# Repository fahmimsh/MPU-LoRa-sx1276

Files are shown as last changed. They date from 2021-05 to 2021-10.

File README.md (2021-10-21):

# MPU-LoRa-sx1276 ESP32 as GATEWAY and Arduino Promini as node multi connection communication
let's get developt it together
This repository program is used for monitoring public transportation such as metroline, MPU, and so on. There are 2 programs, namely node programs installed in vehicles by sending GPS data and gateway programs to receive data from node x vehicles to be sent to the database. Then the passenger android application will be able to find out the location of the vehicle closest to the location of the passenger vehicle.

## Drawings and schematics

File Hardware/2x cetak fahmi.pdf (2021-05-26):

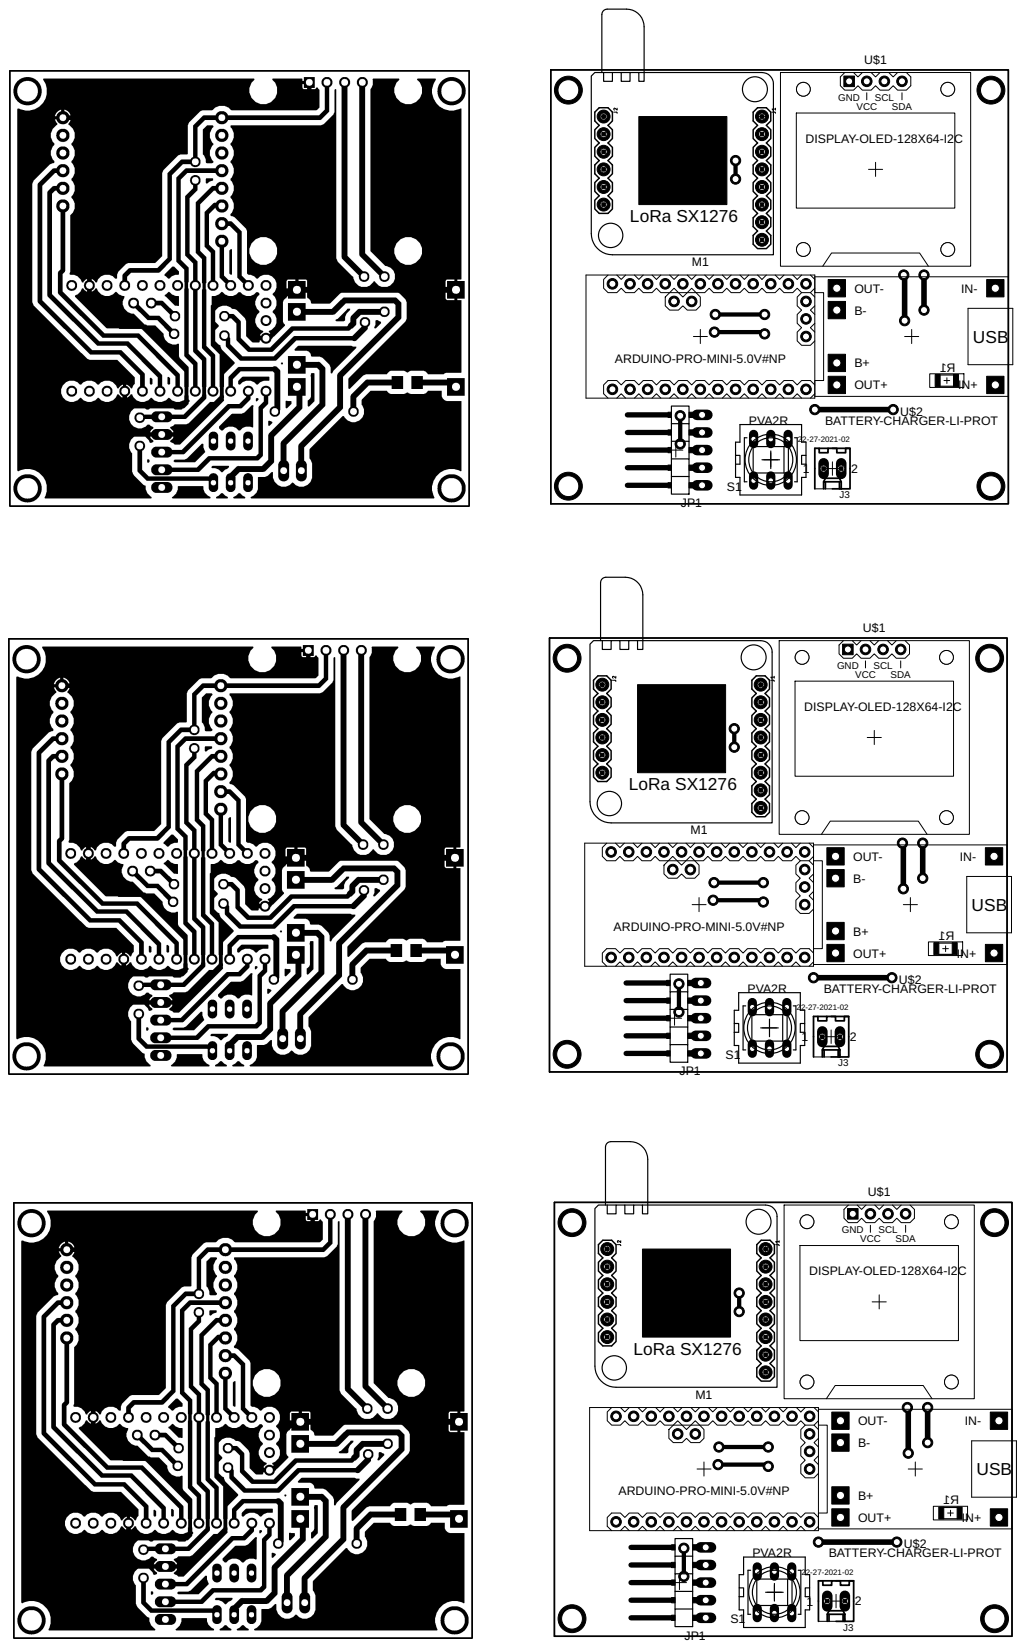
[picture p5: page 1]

ARDUINO-PRO-MINI-5.0V#NP

U$2 BATTERY-CHARGER-LI-PROT

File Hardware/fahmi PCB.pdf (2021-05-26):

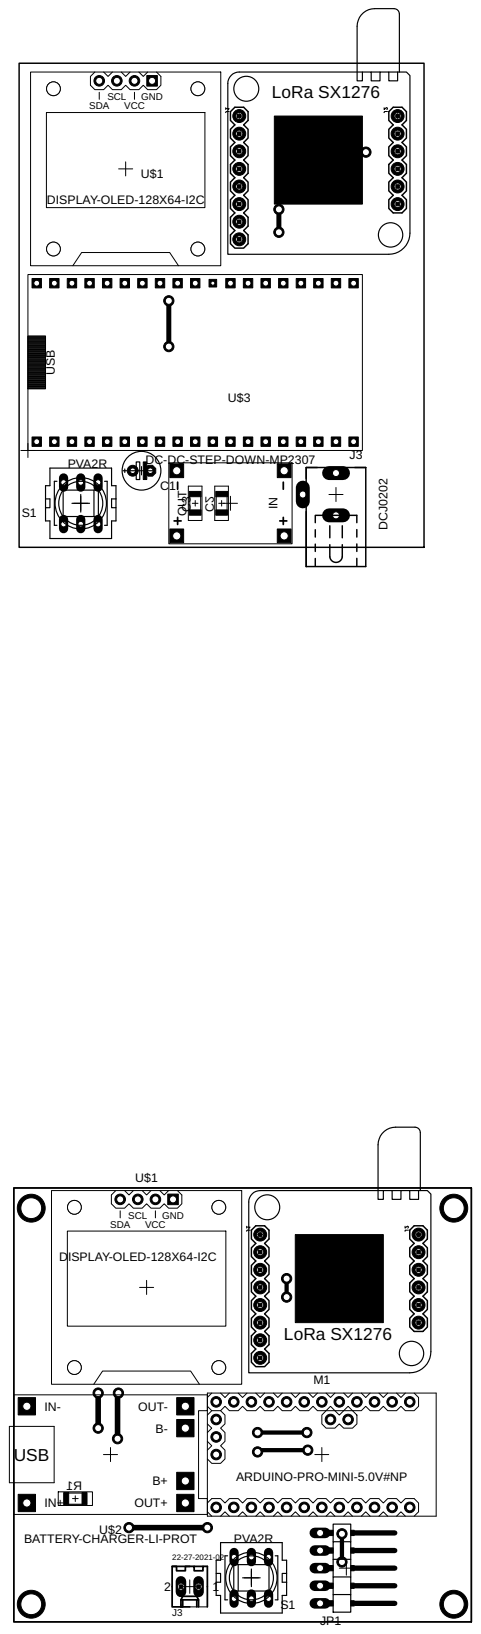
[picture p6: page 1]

ARDUINO-PRO-MINI-5.0V#NP

U$2 BATTERY-CHARGER-LI-PROT

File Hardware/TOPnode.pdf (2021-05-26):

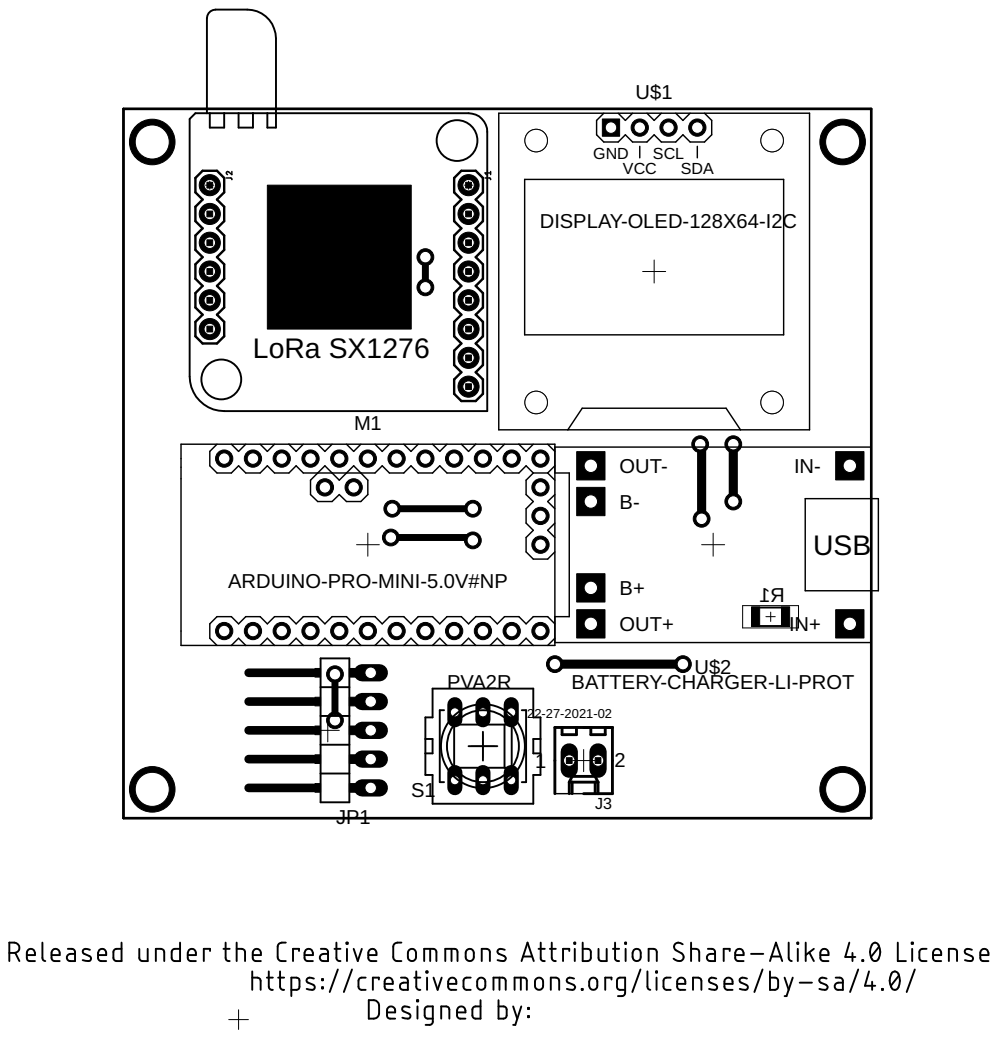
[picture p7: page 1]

ARDUINO-PRO-MINI-5.0V#NP

BATTERY-CHARGER-LI-PROT

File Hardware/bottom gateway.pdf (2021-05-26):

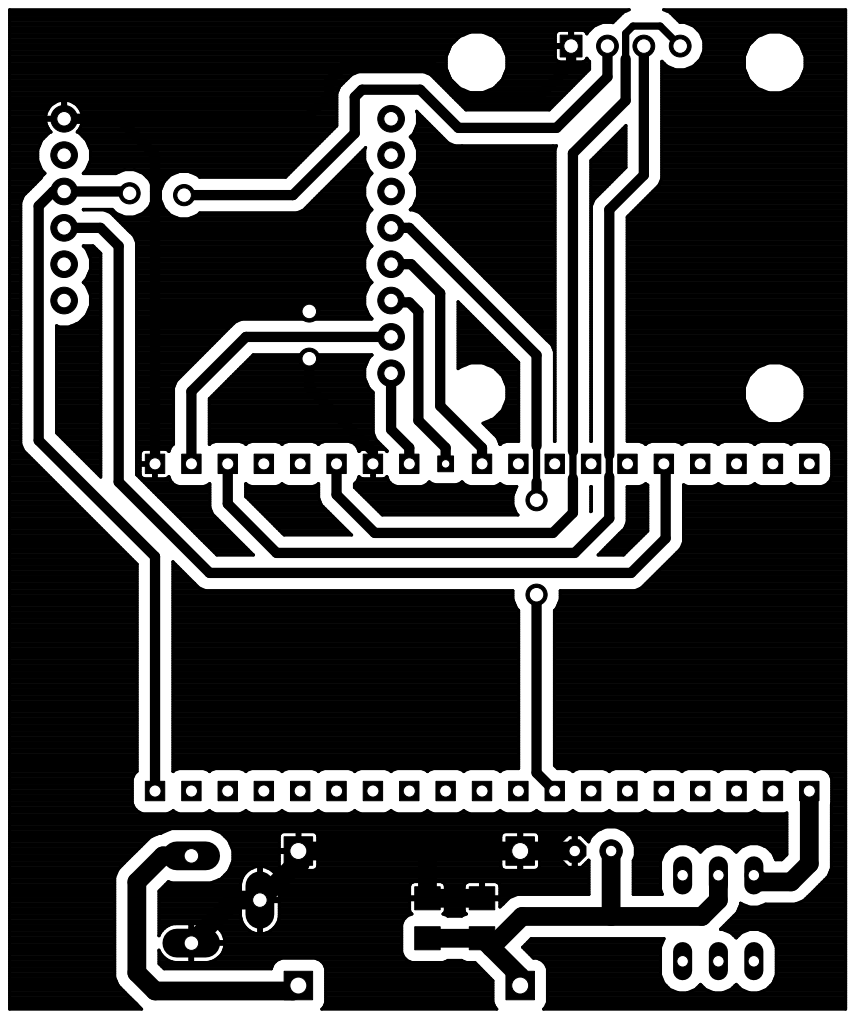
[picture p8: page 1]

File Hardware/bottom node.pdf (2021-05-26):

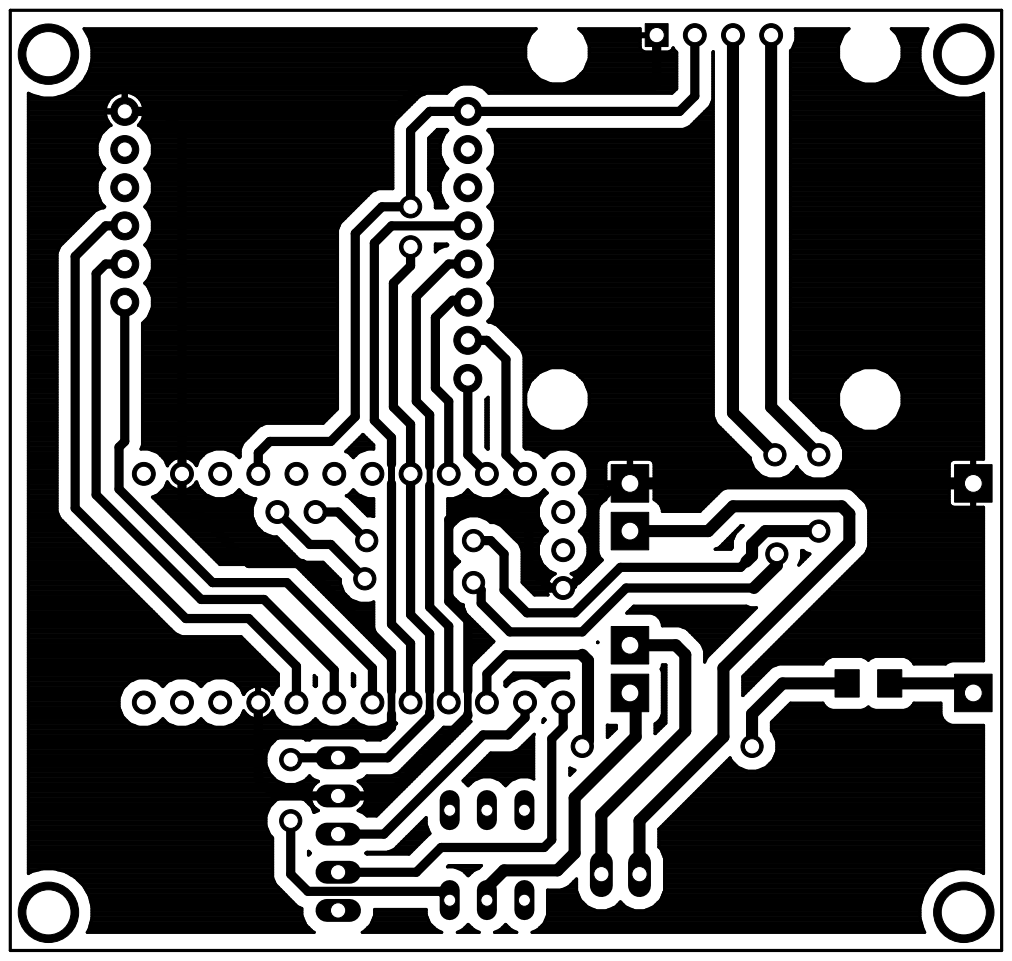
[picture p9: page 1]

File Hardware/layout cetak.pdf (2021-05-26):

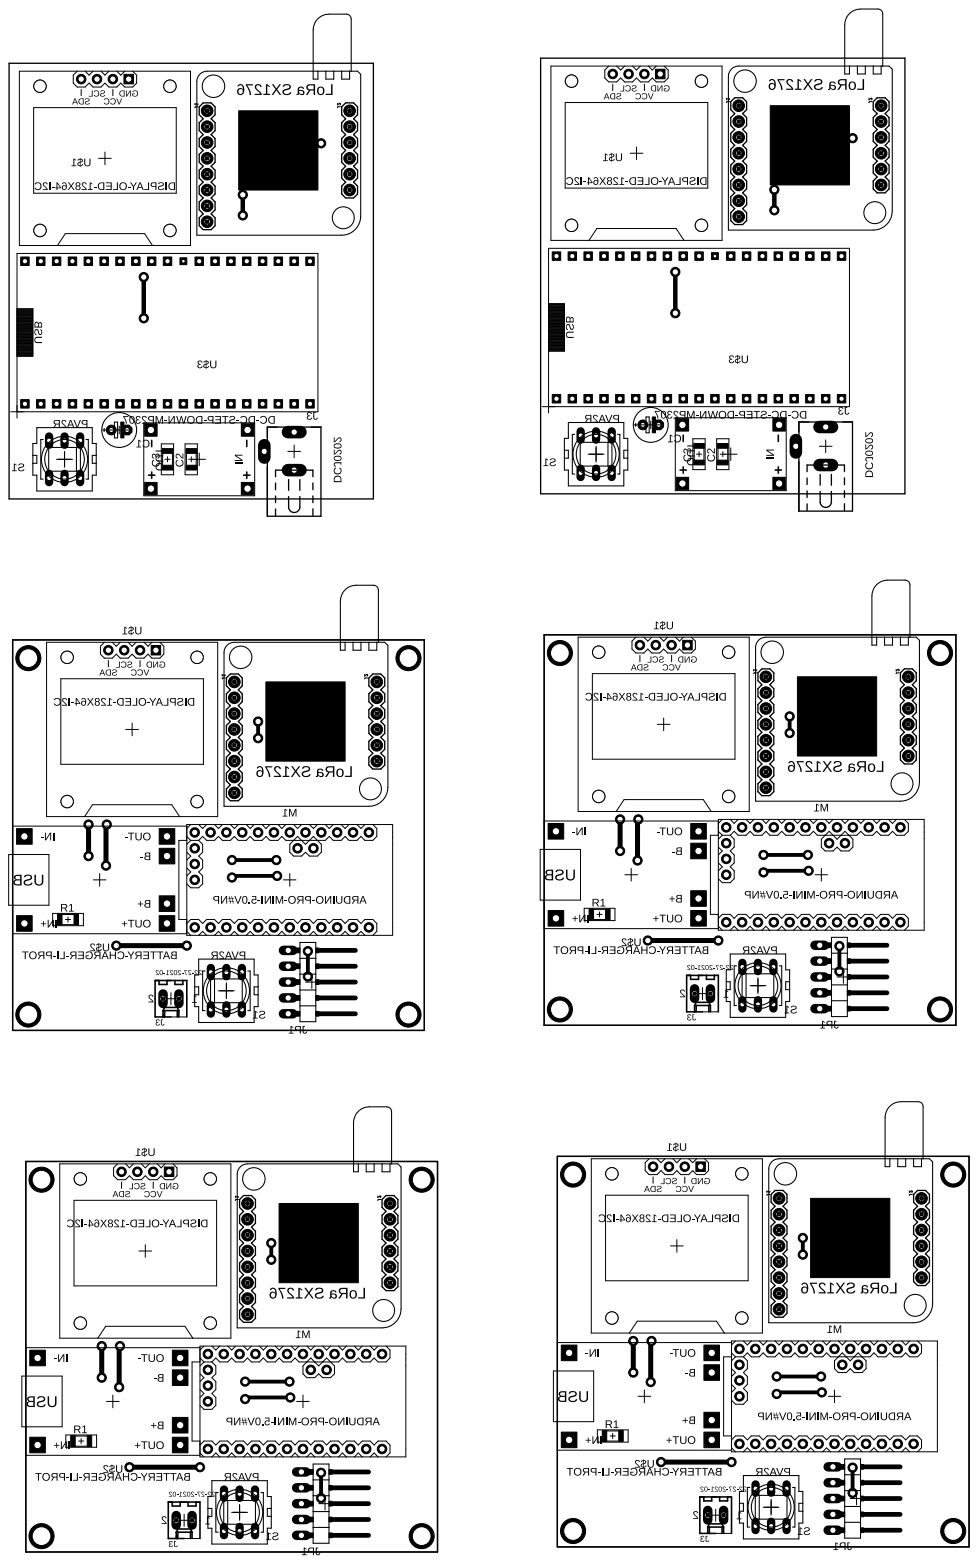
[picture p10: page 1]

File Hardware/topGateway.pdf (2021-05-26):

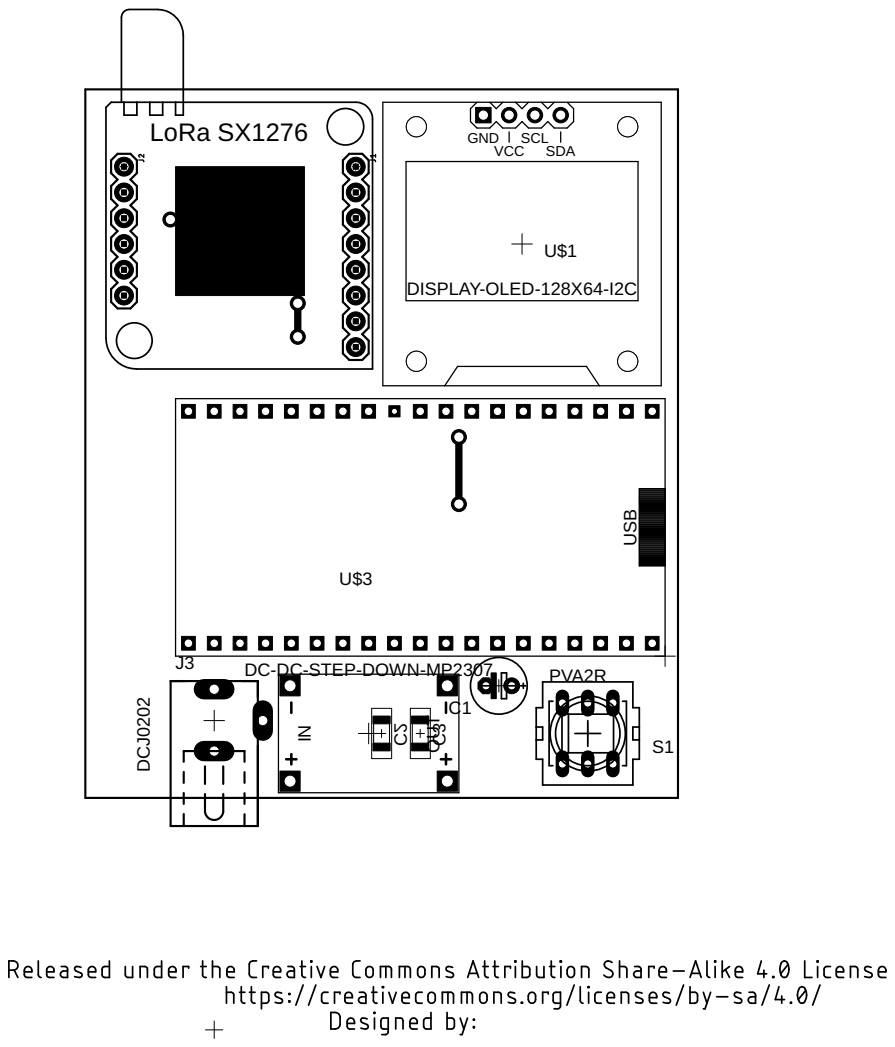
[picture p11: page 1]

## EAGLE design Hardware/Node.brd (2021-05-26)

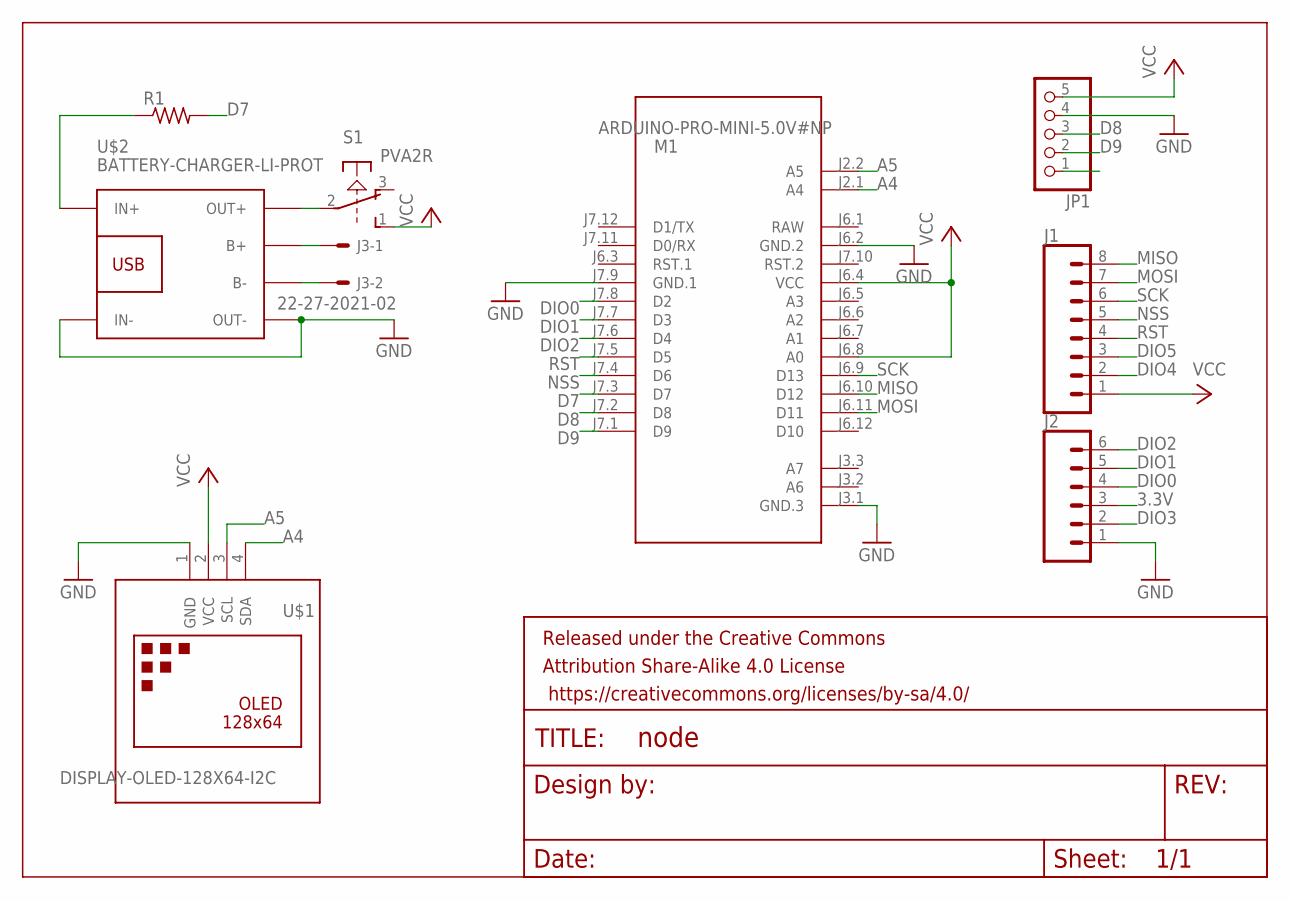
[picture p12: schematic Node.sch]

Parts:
FRAME1: FRAME-LEDGER; CREATIVE_COMMONS
J1: CONN_08"; 1X08
J2: CONN_06SILK_FEMALE_PTH; 1X06
J3: 22-27-2021-02; 6410-02
JP1: PINHD-1X5/90; 1X05/90
M1: ARDUINO-PRO-MINI-5.0V#NP; ARDUINO-PRO-MINI#NP
R1: R-US_R1206; R1206
S1: PVA2R
U$1: DISPLAY-OLED-128X64-I2C
U$2: BATTERY-CHARGER-LI-PROT

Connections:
3.3V: J2.3
A4: M1.J2.1 (A4), U$1.4 (SDA)
A5: M1.J2.2 (A5), U$1.3 (SCL)
D7: M1.J7.3 (D7), R1.2
D8: JP1.3, M1.J7.2 (D8)
D9: JP1.2, M1.J7.1 (D9)
DIO0: J2.4, M1.J7.8 (D2)
DIO1: J2.5, M1.J7.7 (D3)
DIO2: J2.6, M1.J7.6 (D4)
DIO3: J2.2
DIO4: J1.2
DIO5: J1.3
GND: J2.1, JP1.4, M1.J3.1 (GND.3), M1.J6.2 (GND.2), M1.J7.9 (GND.1), U$1.1 (GND), U$2.IN-, U$2.OUT-
MISO: J1.8, M1.J6.10 (D12)
MOSI: J1.7, M1.J6.11 (D11)
unnamed: R1.1, U$2.IN+
unnamed: J3.1, U$2.B+
unnamed: J3.2, U$2.B-
unnamed: S1.2, U$2.OUT+
NSS: J1.5, M1.J7.4 (D6)
RAW: M1.J6.1 (RAW)
RST: J1.4, M1.J7.5 (D5)
SCK: J1.6, M1.J6.9 (D13)
VCC: J1.1, JP1.5, M1.J6.4 (VCC), M1.J6.8 (A0), S1.1 (S), U$1.2 (VCC)

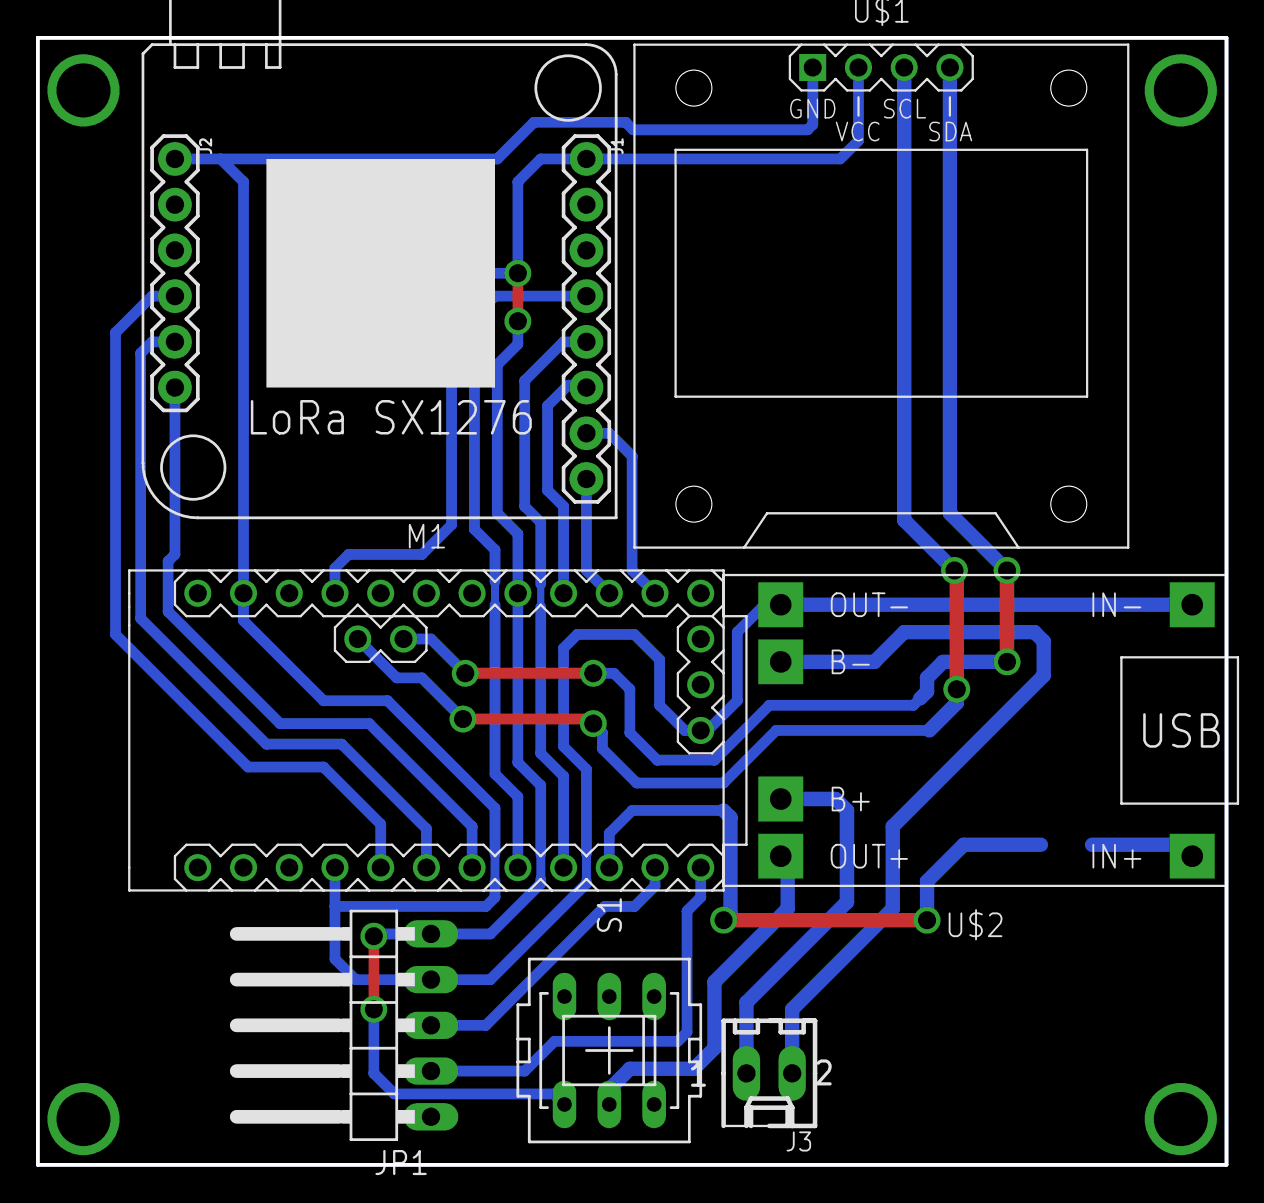
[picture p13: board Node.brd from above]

Board: 2 copper layers, 66.0 x 62.6 mm, 10 parts (1 on the bottom side), 19 nets.

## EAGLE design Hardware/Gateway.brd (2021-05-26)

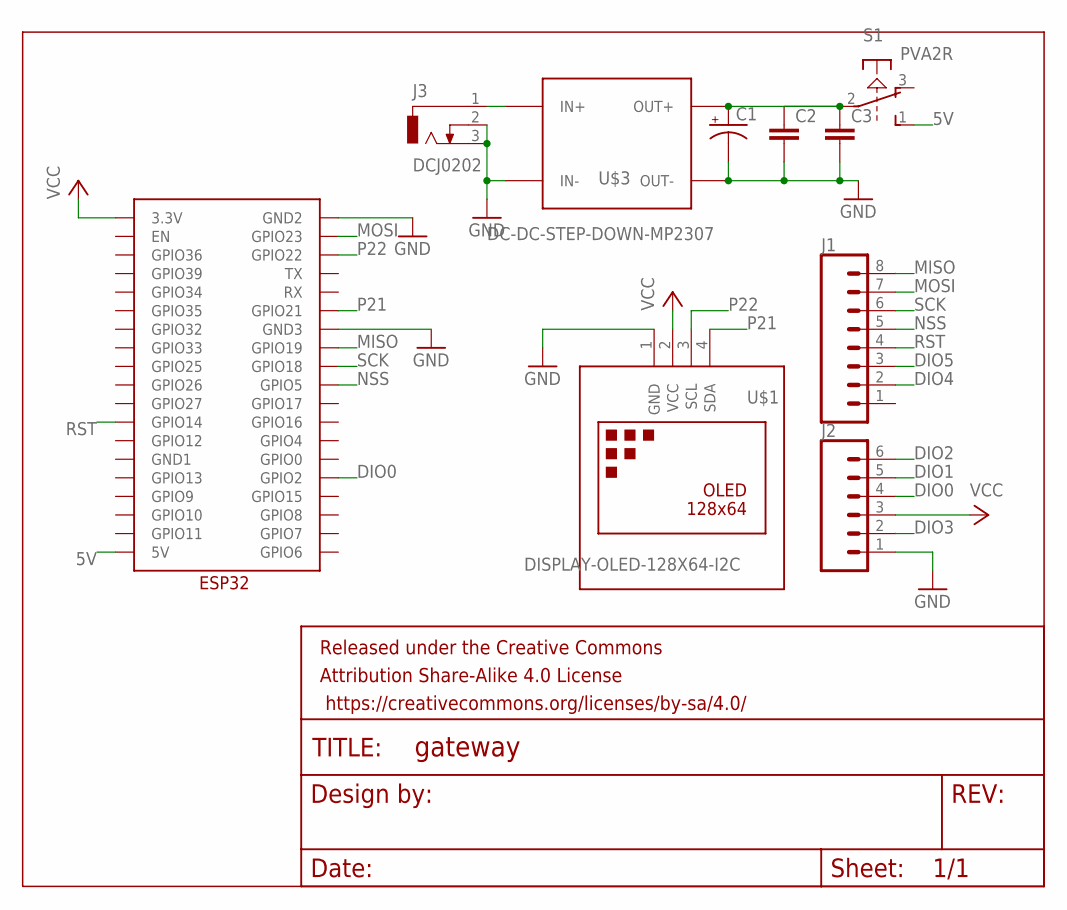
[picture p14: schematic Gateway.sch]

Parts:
C1: CPOL-USE2,5-6E; E2,5-6E
C2, C3: C-EUC1206; C1206
FRAME1: FRAME-LEDGER; CREATIVE_COMMONS
J1: CONN_08"; 1X08
J2: CONN_06SILK_FEMALE_PTH; 1X06
J3: DCJ0202
S1: PVA2R
U$1: DISPLAY-OLED-128X64-I2C
U$2: ESP32
U$3: DC-DC-STEP-DOWN-MP2307

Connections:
5V: S1.1 (S), U$2.5V
DIO0: J2.4, U$2.GPIO2
DIO1: J2.5
DIO2: J2.6
DIO3: J2.2
DIO4: J1.2
DIO5: J1.3
GND: C1.-, C2.2, C3.2, J2.1, J3.2, J3.3, U$1.1 (GND), U$2.GND2, U$2.GND3, U$3.IN-, U$3.OUT-
MISO: J1.8, U$2.GPIO19
MOSI: J1.7, U$2.GPIO23
unnamed: C1.+, C2.1, C3.1, S1.2, U$3.OUT+
unnamed: J3.1, U$3.IN+
NSS: J1.5, U$2.GPIO5
P21: U$1.4 (SDA), U$2.GPIO21
P22: U$1.3 (SCL), U$2.GPIO22
RST: J1.4, U$2.GPIO14
SCK: J1.6, U$2.GPIO18
VCC: J2.3, U$1.2 (VCC), U$2.3.3V

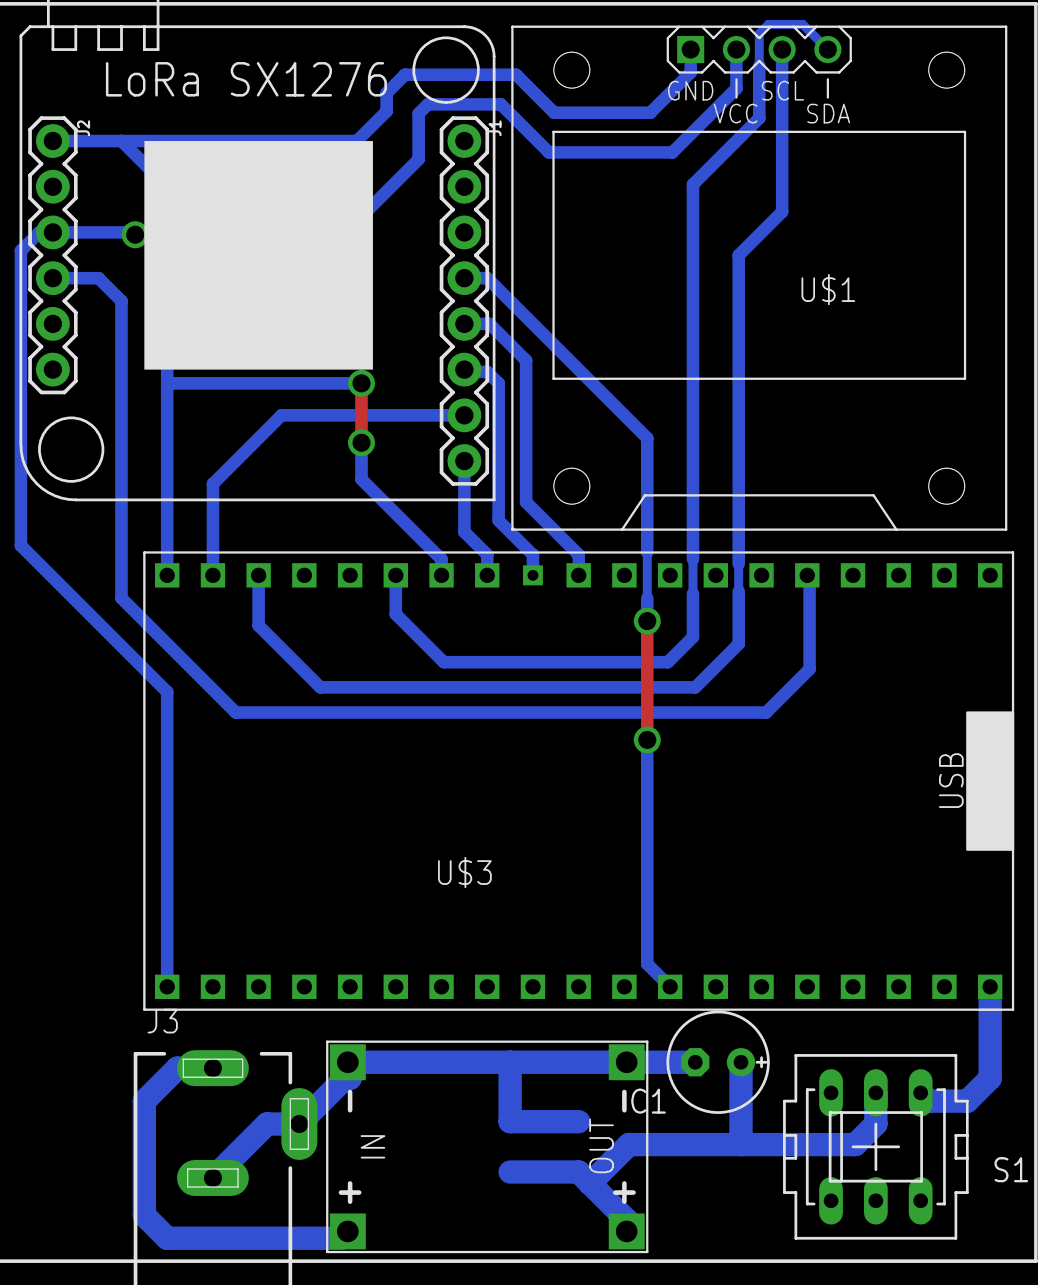
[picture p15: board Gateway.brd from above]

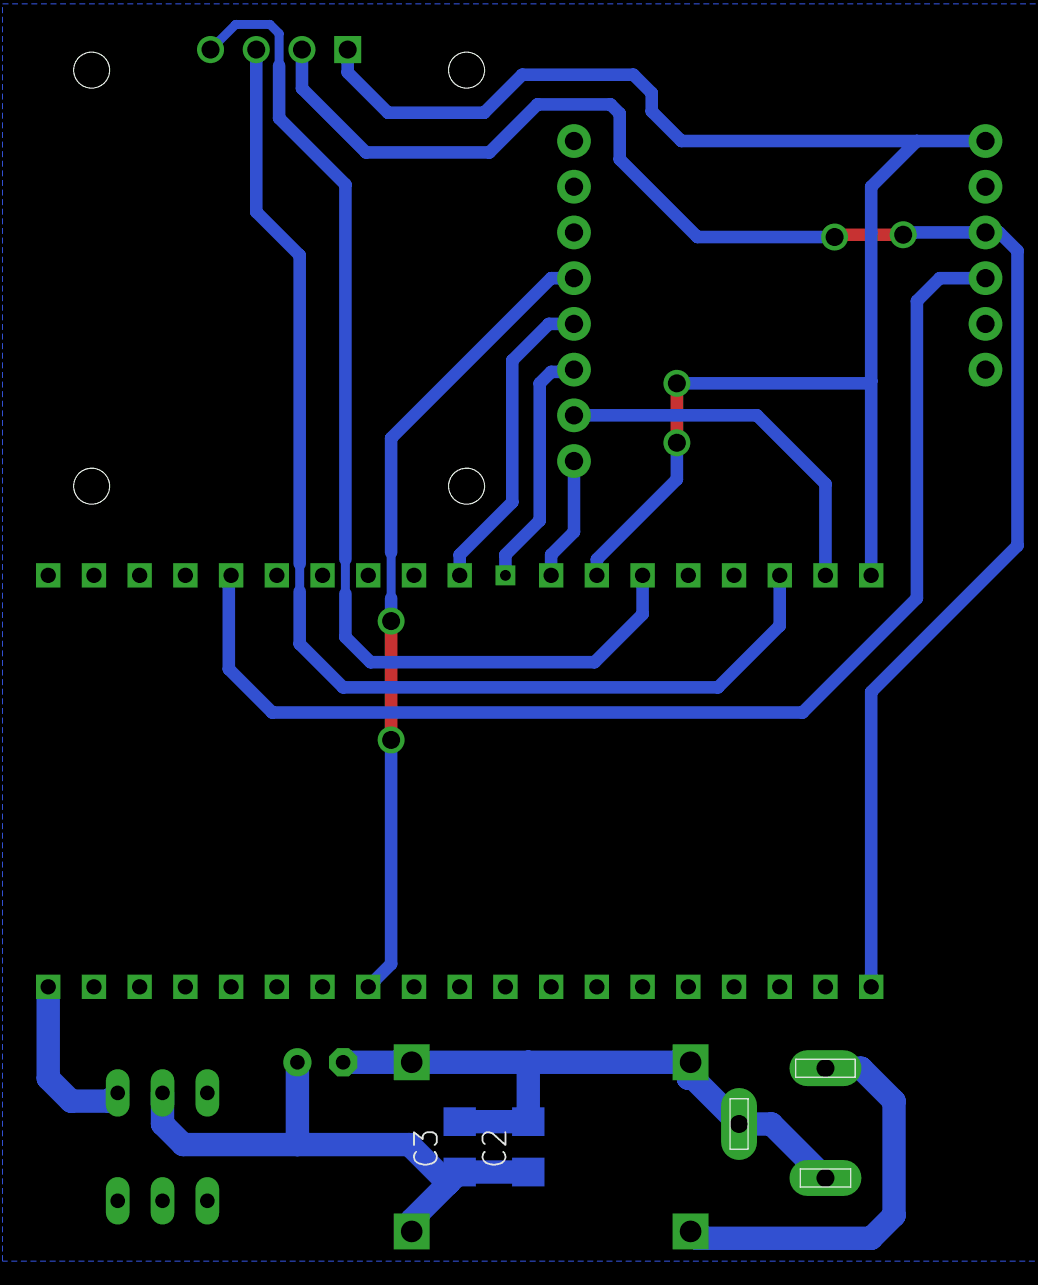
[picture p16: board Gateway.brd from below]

Board: 2 copper layers, 11 parts (2 on the bottom side), 13 nets.

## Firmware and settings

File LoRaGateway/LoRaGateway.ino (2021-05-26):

#include <SPI.h>
#include <LoRa.h>
#include <WiFi.h>
#include <Wire.h>
#include <Adafruit_GFX.h>
#include <Adafruit_SSD1306.h>
#include "FirebaseESP32.h"
#include <stdio.h>

#define FIREBASE_HOST "https://mpu-lora-default-rtdb.firebaseio.com/"
#define FIREBASE_AUTH "M41GfzLBCrY6lqw7bXoHtaOjYBYui1l7Wkcuj94b"
#define csPin 5
#define resetPin 14
#define irqPin 2

const char* ssid="fahmi";
const char* password = "bersiapsiapya";

String dataIn = "", dt[10];
char buff[100];
boolean parsing=false, terima = false;
FirebaseData firebaseData;
FirebaseJson json;

Adafruit_SSD1306 display(128, 64, &Wire, -1);
WiFiClient client_;

void setup() {
  Serial.begin(115200);
  while(!Serial);
  if(!display.begin(SSD1306_SWITCHCAPVCC, 0x3C)) {
    Serial.println(F("SSD1306 allocation failed"));
    for(;;);
  }  delay(2000);
  display.clearDisplay();
  display.setTextColor(WHITE);
  display.setTextSize(2);
  display.setCursor(10, 0);
  display.println("MPU LORA");
  display.setCursor(10, 30);
  display.println("GATEWAY");
  display.display();
  delay(2000);
  Serial.println("LoRa Gateway");
  LoRa.setPins(csPin, resetPin, irqPin);
  Serial.print("Inisialisasi LoRa .");
  if (!LoRa.begin(915E6)) {
    Serial.println(" [FAILED!]");
    while (true); 
  }
  Serial.println(" [OK!]");
  connectWifi();
  displayoled();
  LoRa.onReceive(onReceive);
  LoRa.disableInvertIQ();   //Mode Recheiver
  LoRa.receive();
  //LoRa Setting Komunikasi
//  LoRa.setTxPower(20);
//  LoRa.setSpreadingFactor(10);
//  LoRa.setSignalBandwidth(125E3);
//  //LoRa.setCodingRate4(8);
//  LoRa.setSyncWord(0xE3); //0xE3
//  //LoRa.enableCrc();   
  connectfirebase();
}

void loop() {
  if(runSetiap(1000)){
    LoRa.onReceive(onReceive);
    String header = "/" + dt[0];
    Firebase.setString(firebaseData, "/Node", dt[0]);
    Firebase.setString(firebaseData,  header + "/Node", dt[0]);
    Firebase.setString(firebaseData,  header + "/Latitude", dt[1]);
    Firebase.setString(firebaseData,  header + "/Longlitude", dt[2]);
    Firebase.setString(firebaseData,  header + "/Altitude", dt[3]);
    Firebase.setString(firebaseData,  header + "/Baterai", dt[4]);
    if (!Firebase.setString(firebaseData, "/Node", dt[0])) {
      Serial.print("Upload data Firebase ,MPU LoRa Gagal Dengan data:");
      Serial.println("Node tidak ada");   
      delay(500); 
      return;
    }
    Serial.println();
    Serial.println("Upload data Firebase Berhasil");
    Serial.print("MPU LoRa  Dengan data:");
    Serial.print(" | Node: " + dt[0]);
    Serial.print(" | Latitude: " + dt[1]);
    Serial.print(" | Longlitude : " + dt[2]);
    Serial.print(" | Altitude: " + dt[3]);
    Serial.println(" | Baterai: " + dt[4]);
    Serial.println("___________________________");
  }
  if (terima == true){
    parsingdata();
  }
}
void parsingdata(){//*data1,data2,.....,data100#\n
    parsing = true;
    if(parsing){
      int j=0, i;
      dt[j]="";
      for(i=1;i<dataIn.length();i++){
       if ((dataIn[i] == '#') || (dataIn[i] == ',')){
        j++;
        dt[j]="";
      } else {
        dt[j] = dt[j] + dataIn[i];
      }
    }
    Serial.println("Node: " + dt[0]);
    Serial.println("Latitude: " + dt[1]);
    Serial.println("Longlitude : " + dt[2]);
    Serial.println("Altitude: " + dt[3]);
    Serial.println("Baterai: " + dt[4]);
    Serial.println("___________________________");
    displayoled();
    parsing=false;
    dataIn="";
    }
    terima = false;
}
void onReceive(int packetSize) {
  String Node = "";
  while (LoRa.available()) {
    Node = LoRa.readString();
    Serial.println("data masuk : " + Node);
    //Parsing Data
    terima = true; 
    dataIn += Node;
  }
}
void displayoled(){
    display.clearDisplay();
    display.setTextSize(1);
    display.setCursor(40, 0);
    display.print("MPU LORA");
    display.setCursor(0, 10);
    display.print("Node : ");
    display.println(dt[0]);
    display.setTextSize(1);
    display.setCursor(0, 20);
    display.print("Latitude :");
    display.setCursor(60, 20);
    display.println(dt[1]);

    display.setCursor(0, 30);
    display.print("Longitud :");
    display.setCursor(60, 30);
    display.println(dt[2]);

    display.setCursor(0, 40);
    display.print("Altitude :");
    display.setCursor(60, 40);
    display.println(dt[3]);

    display.setCursor(0, 50);
    display.print("Battery :");
    display.setCursor(80, 50);
    display.println(dt[4] + " V");
    display.display();
}
void connectWifi() {
    Serial.print("Inisialisasi WiFi");  
    WiFi.begin(ssid,password);
    Serial.print("Connecting. ");
    while (WiFi.status() != WL_CONNECTED) {
      delay(500);
      Serial.print(".");
    }
    Serial.println("[OK!]");
    delay(500);
    Serial.println(WiFi.localIP());  
}
void connectfirebase(){
  Firebase.begin(FIREBASE_HOST, FIREBASE_AUTH);
  Firebase.reconnectWiFi(true);
  Serial.println("------------------------------------");
  Serial.println("Connected...Firebase data MPULORA");
}
boolean runSetiap(unsigned long interval)
{
  static unsigned long previousMillis = 0;
  unsigned long currentMillis = millis();
  if (currentMillis - previousMillis >= interval)
  {
    previousMillis = currentMillis;
    return true;
  }
  return false;
}

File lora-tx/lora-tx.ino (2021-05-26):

#include <SPI.h>
#include <LoRa.h>
#include <TinyGPS++.h> 
#include <SoftwareSerial.h> 
#include <stdlib.h>
#include "SSD1306Ascii.h"
#include "SSD1306AsciiAvrI2c.h"

//definisi pin LoRa
#define ss 6
#define rst 5
#define dio0 2
#define batpin A0
#define charger 7

String batstatus, batt;
float VBAT = 0 ;
SoftwareSerial gpsSerial(8,9);//rx,tx 
TinyGPSPlus tinyGPS;
SSD1306AsciiAvrI2c display;

void setup() {
  Serial.begin(115200);
  pinMode(batpin, INPUT);
  pinMode(charger, INPUT);
  display.begin(&Adafruit128x64, 0x3C);
  display.setFont(System5x7);
  display.clear();
  display.set2X();
  display.setFont(Callibri11_bold);
  display.setCursor(10, 0);
  display.println("MPU LORA");
  display.setCursor(10, 30);
  display.println(" NODE 2");
  delay(2000);
  
  analogReference(INTERNAL);
  while (!Serial);
  Serial.println("LoRa Sender");

  //Atur LoRa transceiver module
  LoRa.setPins(ss, rst, dio0);
  
  //433E6 for Asia
  //866E6 for Europe
  //915E6 for North America
  while (!LoRa.begin(915E6)) {
    Serial.println(".");
    delay(500);
  }
   // Change sync word (0xF3) to match the receiver
  // The sync word assures you don't get LoRa messages from other LoRa transceivers
  // ranges from 0-0xFF
  LoRa.setSyncWord(0xF3);
  Serial.println("LoRa Initializing OK!");
  gpsSerial.begin(9600);
  Serial.println("GPS Initialized");
  Serial.println("Waiting for GPS.. .");
  LoRa.beginPacket();
  Serial.println(gpsSerial.read());
  LoRa.print("Waiting for GPS...");
  LoRa.endPacket();
  Serial.println("inisialisasi selesai");
  Serial.println("___________________________");
}
void loop() {
    printGPSInfo();
    baterai();
    dataOled();
    smartDelay(1000); 
}
void dataOled(){
    display.setFont(System5x7);
    display.set1X();
    display.setFont(Callibri11_bold);
    display.clear();
    display.setCursor(0, 20);
    display.print("Latitude :");
    display.setCursor(50, 20);
    display.println(tinyGPS.location.lat(),6);

    display.setCursor(0, 30);
    display.print("Longitud:");
    display.setCursor(50, 30);
    display.println(tinyGPS.location.lng(),6);

    display.setCursor(0, 40);
    display.print("Altitude :");
    display.setCursor(50, 40);
    display.println(tinyGPS.altitude.meters());

    display.setCursor(0, 50);
    display.println(batstatus);

    if (digitalRead(charger) == HIGH){
      display.setCursor(90, 50);
      display.println("Charger"); 
    }
}
void printGPSInfo() {
    LoRa.beginPacket();
    //kirim text *1,lat,long,altitude,baterai#\n
    LoRa.print("*1,");
    LoRa.print(tinyGPS.location.lat(),6);
    LoRa.print(",");
    LoRa.print(tinyGPS.location.lng(),6);
    LoRa.print(",");
    LoRa.print(tinyGPS.altitude.meters());
    LoRa.print(",");
    LoRa.print(batt);
    LoRa.println("#"); 
    LoRa.endPacket();
    
    Serial.print("Lat: "); Serial.println(tinyGPS.location.lat(),6);
    Serial.print("Long : "); Serial.println(tinyGPS.location.lng(),6);
    Serial.print("Altitude: "); Serial.println(tinyGPS.altitude.meters()); 
    Serial.println("___________________________");
}
void baterai(){
  //baterai
  float r1=26820.0;
  float r2=100000.0;
  //VBAT = ((((3.3f*analogRead(batpin))/1024)/ r2*(r1+r2)) );
  VBAT = ((3.3f*analogRead(batpin))/1024);
  batt = String(VBAT, 2);
  batstatus = "Battery  : " + String(VBAT, 2) + " V";
  Serial.println(batstatus);
}
static void smartDelay(unsigned long ms)
{
  unsigned long start = millis();
  do
  {
    while (gpsSerial.available())
      tinyGPS.encode(gpsSerial.read());
  } while (millis() - start < ms);
}

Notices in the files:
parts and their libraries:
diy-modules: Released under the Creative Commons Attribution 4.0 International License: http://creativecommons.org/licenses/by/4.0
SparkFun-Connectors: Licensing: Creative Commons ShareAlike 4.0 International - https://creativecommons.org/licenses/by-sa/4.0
